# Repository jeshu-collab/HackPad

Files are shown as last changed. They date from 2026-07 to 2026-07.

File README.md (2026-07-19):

# HackPad1

HackPad1 is a custom 9-key macropad built using the Seeed XIAO RP2040. It includes a rotary encoder, a 128x32 OLED display, and per-key RGB lighting. The firmware is written using KMK, making it easy to customize key mappings and add new features.

This project was designed from scratch, including the PCB, enclosure, and firmware.

---

## Features

- 9-key mechanical macropad (3x3 layout)
- EC11 rotary encoder for volume control
- 128x32 OLED display
- Per-key RGB using SK6812MINI-E LEDs
- Powered by Seeed XIAO RP2040
- KMK firmware for easy customization
- Custom 2-piece 3D printed enclosure

---

## CAD Model

The enclosure is designed as a two-piece case.

- **Top Shell:** Holds the switches and has the outer frame.
- **Bottom Plate:** Closes the enclosure and supports the PCB.

### Overall View

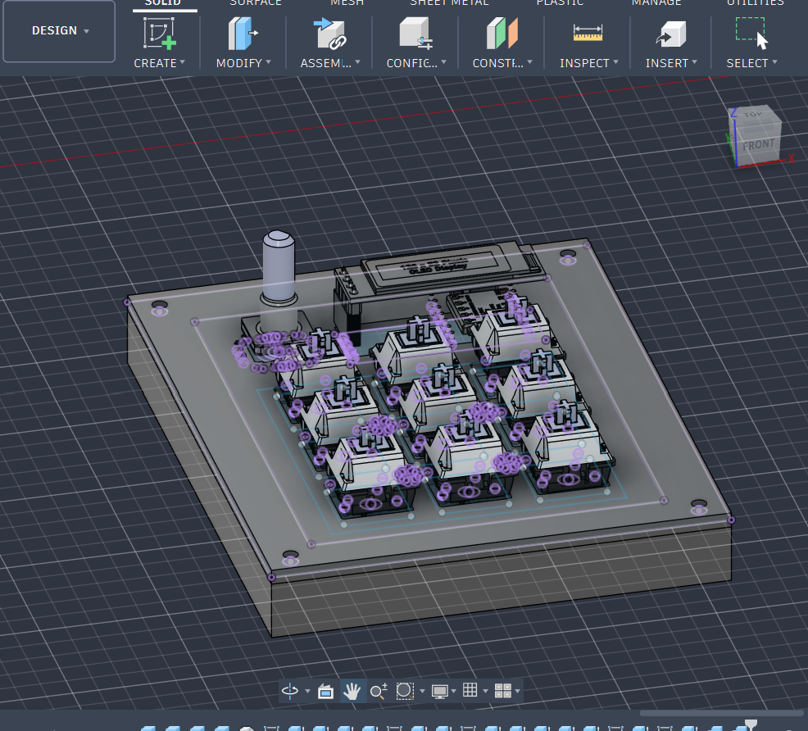
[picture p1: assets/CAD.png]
Overall Hackpad


### Case Assembly

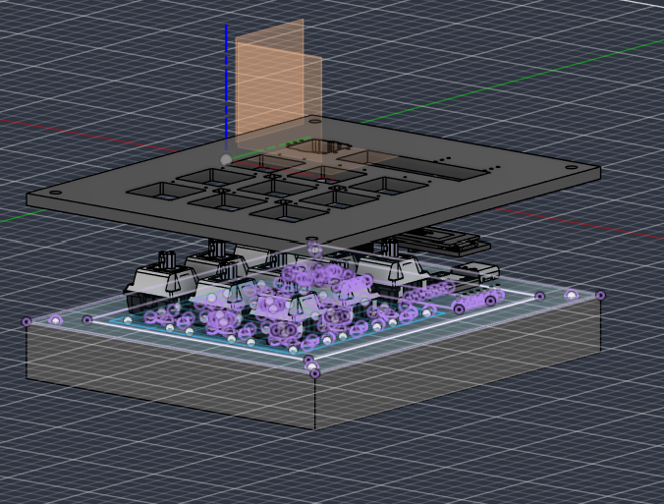
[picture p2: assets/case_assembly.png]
Case Assembly


---

## PCB

The PCB was designed in KiCad. It includes the switch matrix, rotary encoder, OLED display connections, RGB LEDs, and the XIAO RP2040.

### Schematic

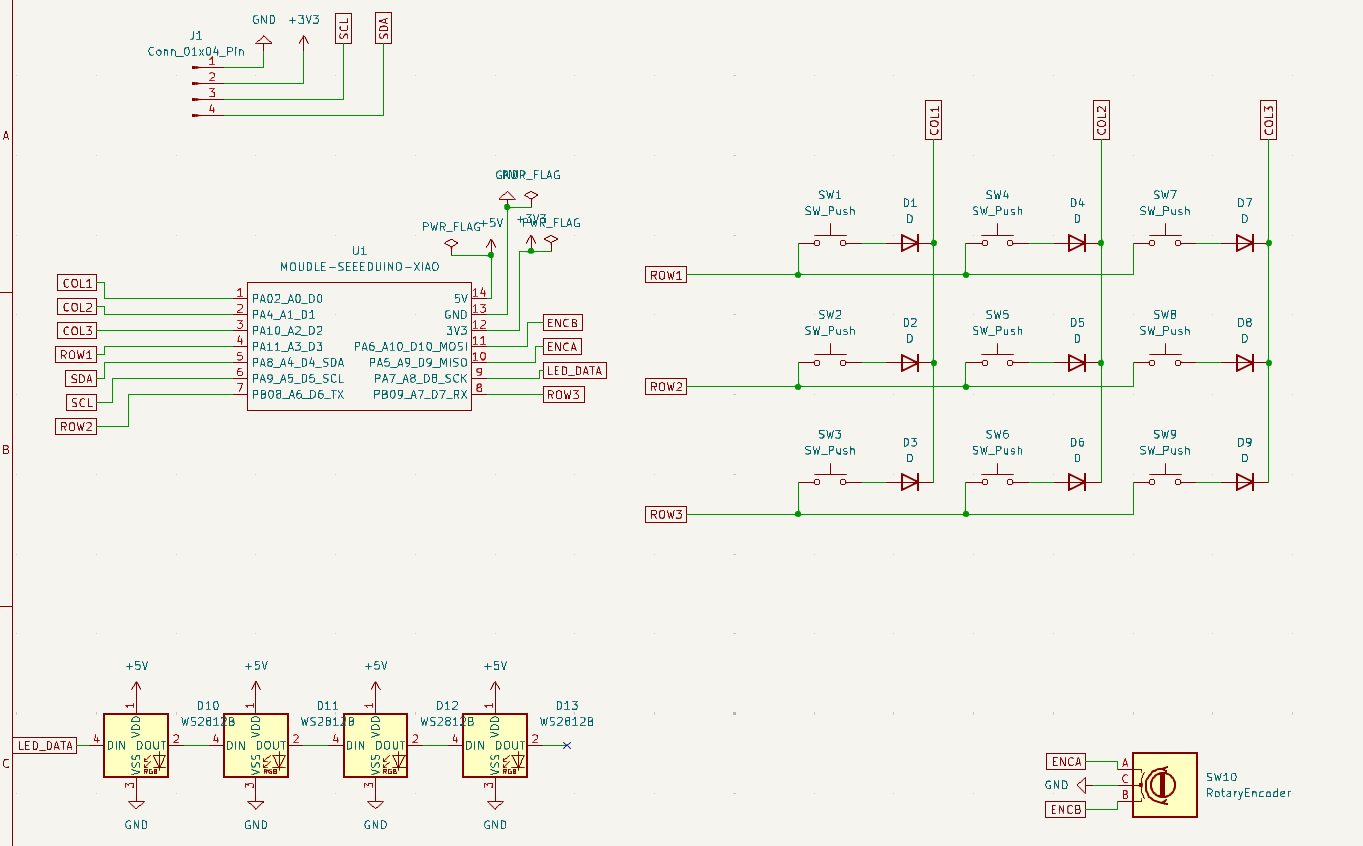
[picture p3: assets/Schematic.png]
Schematic


### PCB Layout

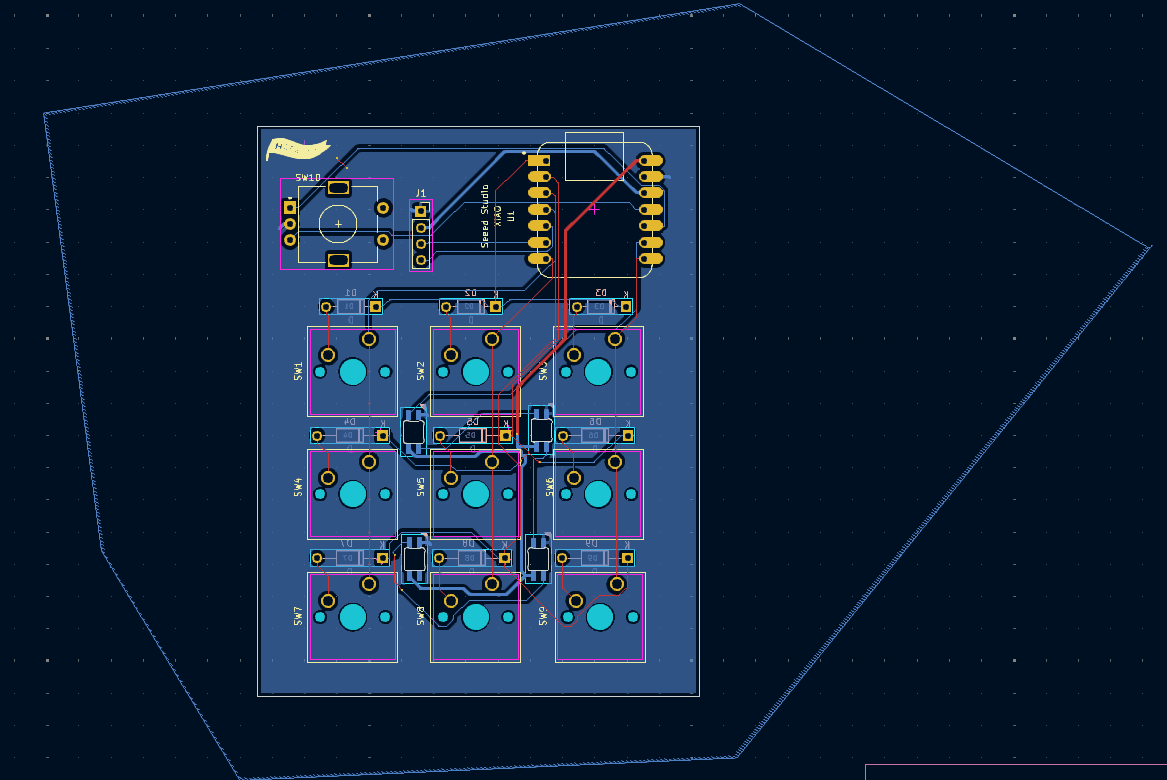
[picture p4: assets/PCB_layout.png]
PCB


---

## Firmware

The firmware is based on **KMK**.

Current functionality:

- Rotary encoder controls system volume.
- Pressing the encoder mutes/unmutes the audio.
- The 9 keys are currently mapped as number keys (1–9).
- OLED displays a startup message.

Key mappings can be easily changed by editing `main.py`.

---

## Bill of Materials (BOM)

| Component | Quantity |
|---|---:|
| Cherry MX Switches | 9 |
| Keycaps | 9 |
| 1N4148 Diodes | 9 |
| SK6812MINI-E RGB LEDs | 9 |
| 0.91" 128x32 OLED Display | 1 |
| EC11 Rotary Encoder | 1 |
| Seeed XIAO RP2040 | 1 |
| 3D Printed Enclosure | 1 Set |
| M3 Screws *(update after final assembly)* | As Required |

---

## Future Improvements

- Add multiple layers and shortcuts
- OLED status indicators
- RGB lighting effects
- VIA/Vial-style configuration (if supported)
- Improve case design after testing the first prototype

---

## Acknowledgements

This project was built as part of the Hack Club HackPad initiative.

Special thanks to the Hack Club community for the resources and guidance throughout the build.

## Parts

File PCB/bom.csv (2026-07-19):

Reference | Value | Datasheet | Footprint | Qty | DNP
D1,D2,D3,D4,D5,D6,D7,D8,D9 | D | ~ | -- mixed values -- | 9
D10,D11,D12,D13 | WS2812B | https://cdn-shop.adafruit.com/datasheets/WS2812B.pdf | Keyboard_Parts:MX_SK6812MINI-E | 4
J1 | Conn_01x04_Pin | ~ | Connector_PinSocket_2.54mm:PinSocket_1x04_P2.54mm_Vertical | 1
SW1,SW2,SW3,SW4,SW5,SW6,SW7,SW8,SW9 | SW_Push | ~ | Button_Switch_Keyboard:SW_Cherry_MX_1.00u_PCB | 9
SW10 | RotaryEncoder | ~ | Rotary_Encoder:RotaryEncoder_Alps_EC11E-Switch_Vertical_H20mm | 1
U1 | MOUDLE-SEEEDUINO-XIAO |  | footprints:XIAO-Generic-Hybrid-14P-2.54-21X17.8MM | 1

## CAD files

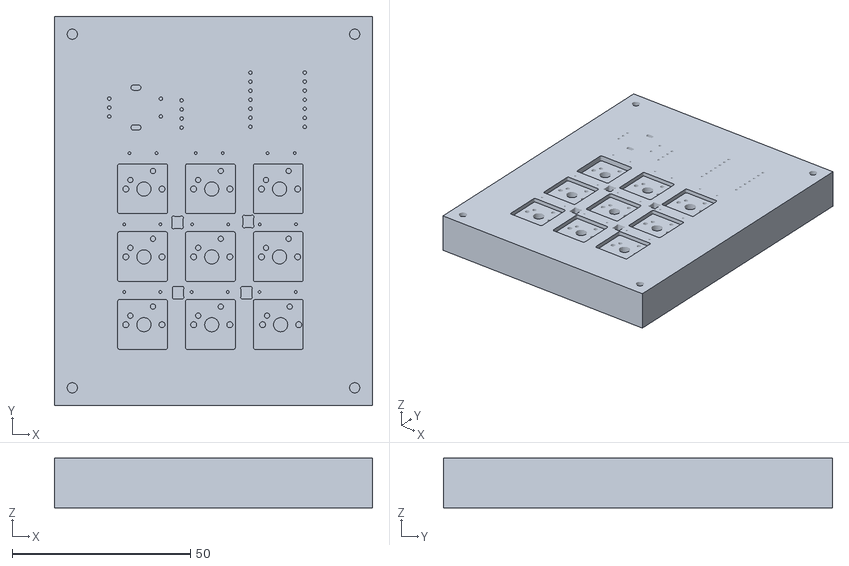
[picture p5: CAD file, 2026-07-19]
Production/Bottom.stl
89.3 x 109.3 x 14.0

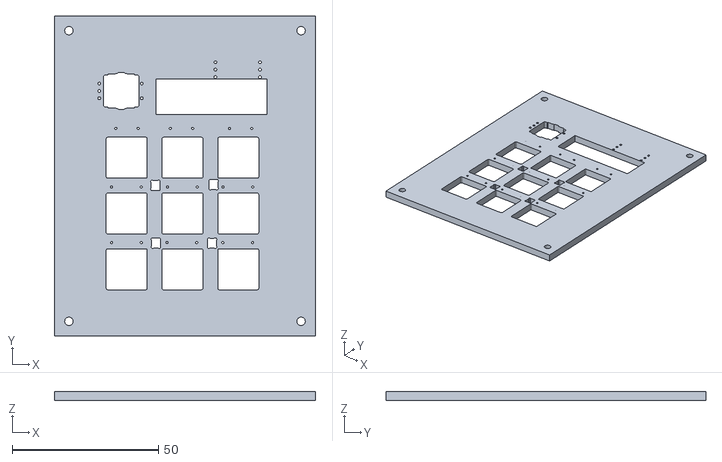
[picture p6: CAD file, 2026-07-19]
Production/Top.stl
89.3 x 109.3 x 3.00

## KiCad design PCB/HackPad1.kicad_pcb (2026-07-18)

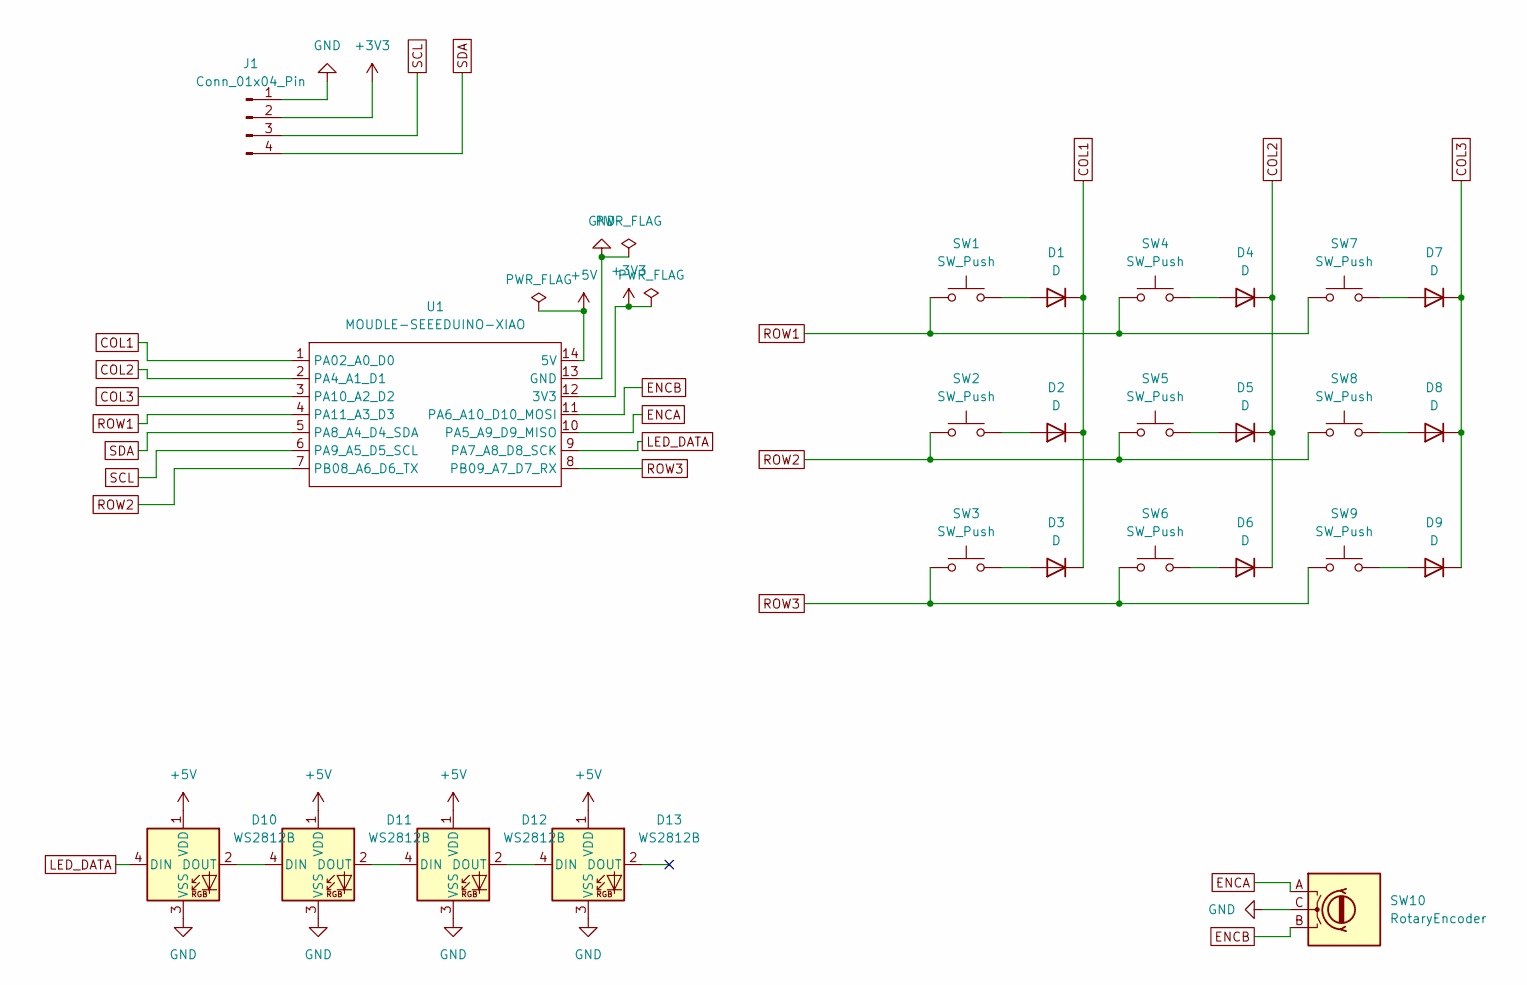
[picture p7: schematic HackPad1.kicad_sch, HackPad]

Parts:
D1, D2, D3: D; D_DO-35_SOD27_P7.62mm_Horizontal
D4, D5, D6, D7, D8, D9: D; D_DO-35_SOD27_P10.16mm_Horizontal
D10, D11, D12, D13: WS2812B; MX_SK6812MINI-E
J1: Conn_01x04_Pin; PinSocket_1x04_P2.54mm_Vertical
SW1, SW2, SW3, SW4, SW5, SW6, SW7, SW8, SW9: SW_Push; SW_Cherry_MX_1.00u_PCB
SW10: RotaryEncoder; RotaryEncoder_Alps_EC11E-Switch_Vertical_H20mm
U1: MOUDLE-SEEEDUINO-XIAO; XIAO-Generic-Hybrid-14P-2.54-21X17.8MM

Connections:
+3V3: J1.2, U1.12 (3V3)
+5V: D10.1 (VDD), D11.1 (VDD), D12.1 (VDD), D13.1 (VDD), U1.14 (5V)
COL1: D1.1 (K), D2.1 (K), D3.1 (K), U1.1 (PA02_A0_D0)
COL2: D4.1 (K), D5.1 (K), D6.1 (K), U1.2 (PA4_A1_D1)
COL3: D7.1 (K), D8.1 (K), D9.1 (K), U1.3 (PA10_A2_D2)
ENCA: SW10.A, U1.10 (PA5_A9_D9_MISO)
ENCB: SW10.B, U1.11 (PA6_A10_D10_MOSI)
GND: D10.3 (VSS), D11.3 (VSS), D12.3 (VSS), D13.3 (VSS), J1.1, SW10.C, U1.13 (GND)
LED_DATA: D10.4 (DIN), U1.9 (PA7_A8_D8_SCK)
unnamed: D1.2 (A), SW1.2
unnamed: D2.2 (A), SW2.2
unnamed: D3.2 (A), SW3.2
unnamed: D4.2 (A), SW4.2
unnamed: D5.2 (A), SW5.2
unnamed: D6.2 (A), SW6.2
unnamed: D7.2 (A), SW7.2
unnamed: D8.2 (A), SW8.2
unnamed: D9.2 (A), SW9.2
unnamed: D10.2 (DOUT), D11.4 (DIN)
unnamed: D11.2 (DOUT), D12.4 (DIN)
unnamed: D12.2 (DOUT), D13.4 (DIN)
ROW1: SW1.1, SW4.1, SW7.1, U1.4 (PA11_A3_D3)
ROW2: SW2.1, SW5.1, SW8.1, U1.7 (PB08_A6_D6_TX)
ROW3: SW3.1, SW6.1, SW9.1, U1.8 (PB09_A7_D7_RX)
SCL: J1.3, U1.6 (PA9_A5_D5_SCL)
SDA: J1.4, U1.5 (PA8_A4_D4_SDA)

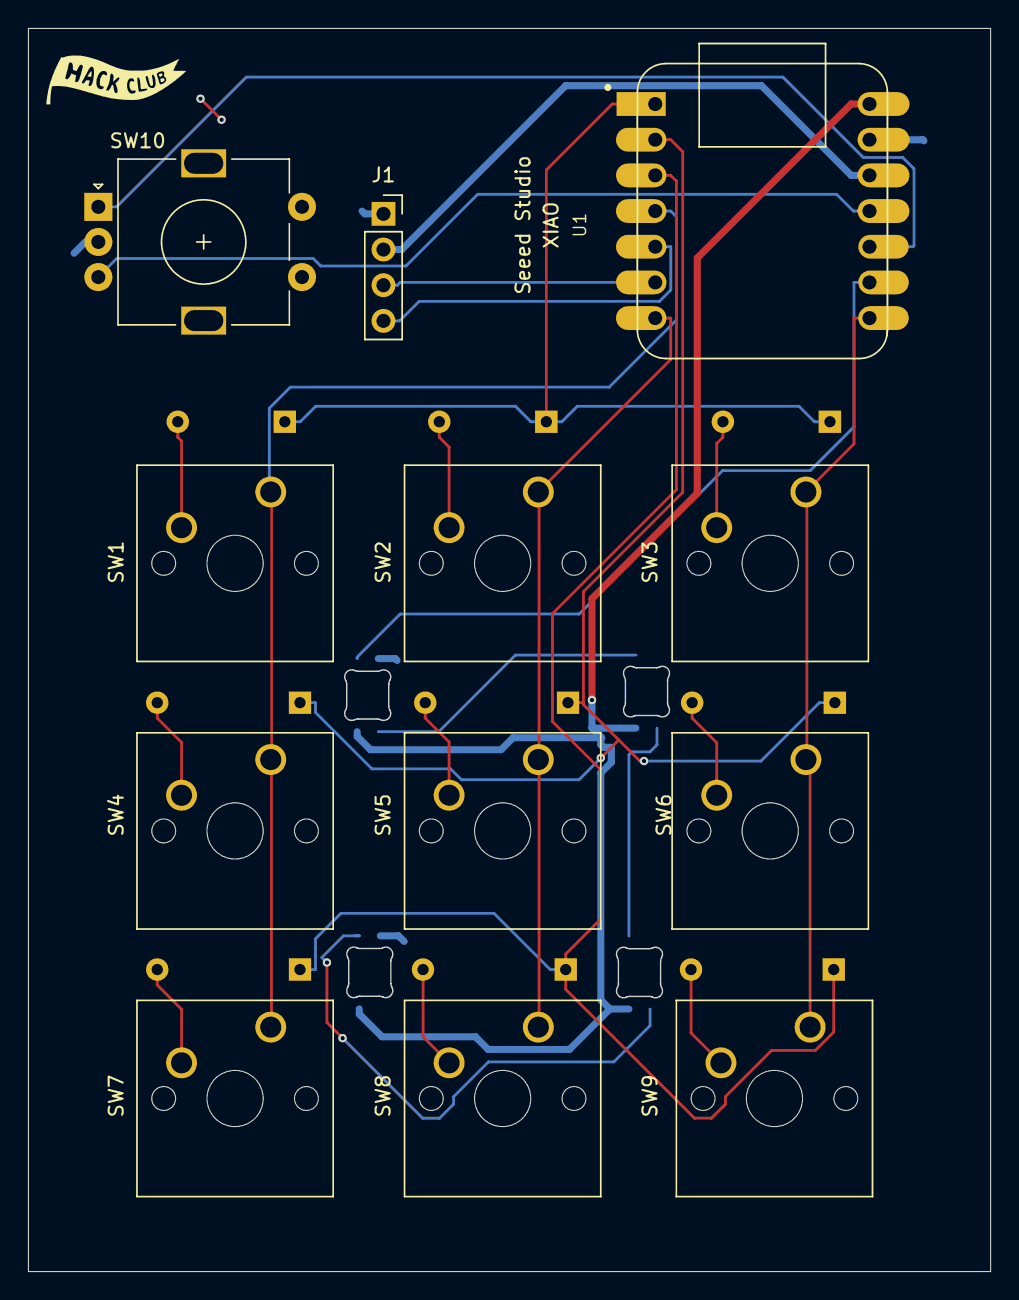
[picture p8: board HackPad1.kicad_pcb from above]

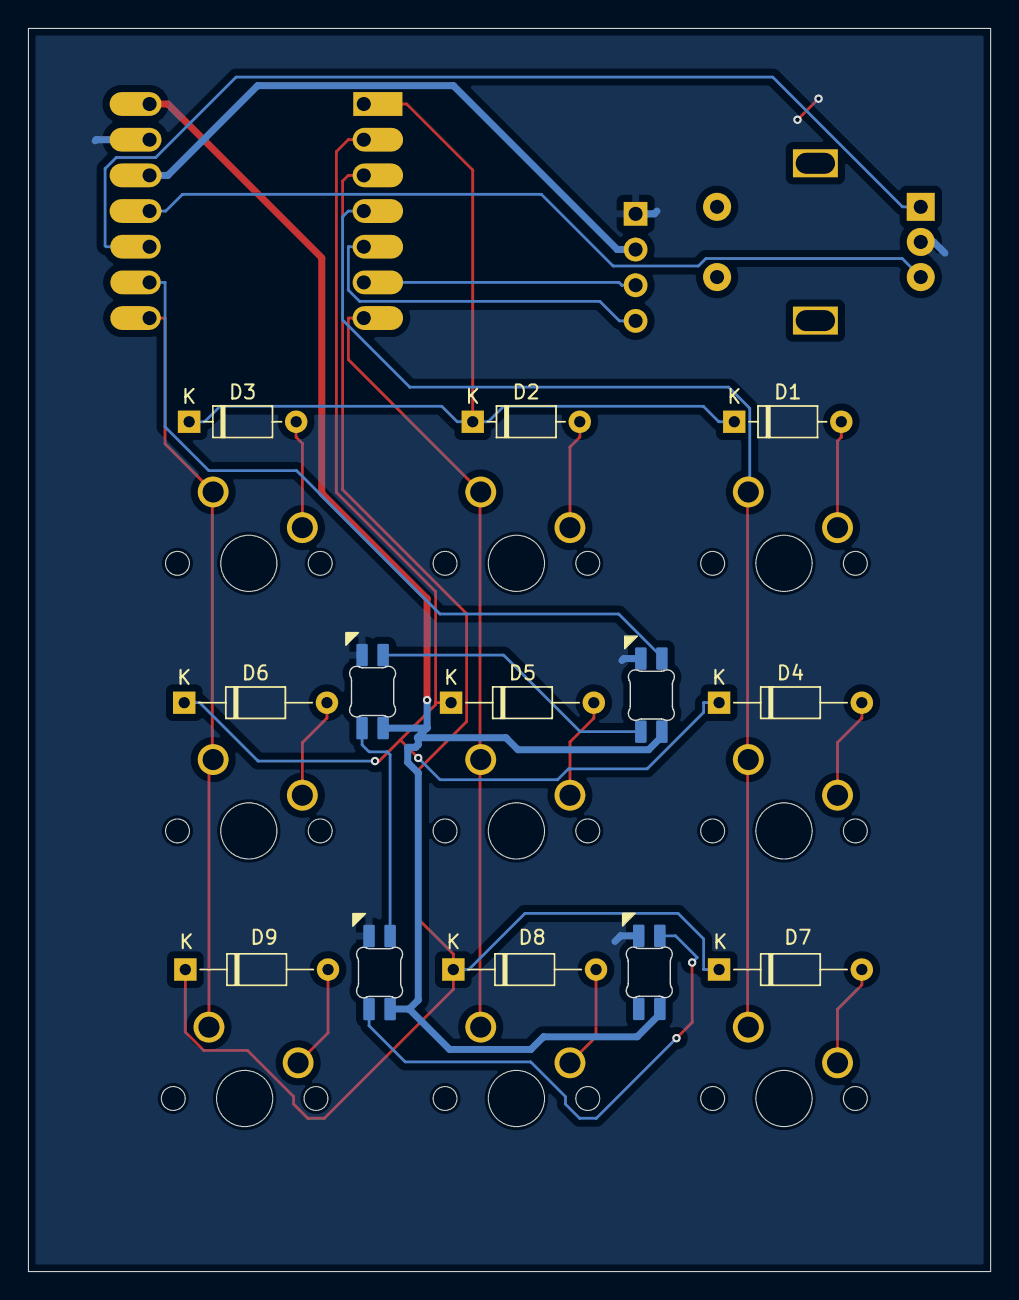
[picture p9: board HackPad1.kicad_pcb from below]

Board: 2 copper layers, 68.5 x 88.5 mm, 25 parts (9 on the bottom side), 26 nets.

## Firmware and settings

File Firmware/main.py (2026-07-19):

code = """import board
import busio
from kmk.kmk_keyboard import KMKKeyboard
from kmk.keys import KC
from kmk.scanners import DiodeOrientation
from kmk.modules.encoder import EncoderHandler
from kmk.modules.layers import Layers
from kmk.extensions.rgb import RGB
from kmk.extensions.display import Display, TextEntry
from kmk.extensions.display.ssd1306 import SSD1306

# Initialize the keyboard
keyboard = KMKKeyboard()

# Add standard modules
keyboard.modules.append(Layers())
encoder_handler = EncoderHandler()
keyboard.modules.append(encoder_handler)

# --- SWITCH MATRIX SETUP ---
keyboard.col_pins = (board.GP0, board.GP1, board.GP2)
keyboard.row_pins = (board.GP3, board.GP4, board.GP5)
keyboard.diode_orientation = DiodeOrientation.COL2ROW

# --- ENCODER SETUP ---
encoder_handler.pins = ((board.GP26, board.GP27, board.GP28, False),)
encoder_handler.map = [
    ((KC.VOLD, KC.VOLU, KC.MUTE),)
]

# --- RGB LED SETUP (SK6812MINI-E) ---
# Replace board.GP29 with your actual LED data pin from KiCad
rgb = RGB(
    pixel_pin=board.GP29,
    num_pixels=9, # Number of LEDs in your matrix
    val_limit=100, # Brightness limit
    hue_default=0,
    sat_default=255,
    val_default=100
)
keyboard.extensions.append(rgb)

# --- OLED DISPLAY SETUP (128x32) ---
# Replace GP7 (SDA) and GP6 (SCL) with your actual I2C pins
i2c_bus = busio.I2C(board.GP7, board.GP6)
display_driver = SSD1306(i2c=i2c_bus, device_address=0x3C)
display = Display(
    display=display_driver,
    entries=[
        TextEntry(text='Hackpad Ready!', x=0, y=0, y_anchor='M'),
    ],
    width=128,
    height=32,
    dim_time=10,
    dim_target=0.2,
    off_time=1200,
    return_to_base=True
)
keyboard.extensions.append(display)

# --- KEYMAP ---
keyboard.keymap = [
    [
        KC.N1, KC.N2, KC.N3,
        KC.N4, KC.N5, KC.N6,
        KC.N7, KC.N8, KC.N9
    ]
]

if __name__ == '__main__':
    keyboard.go()
"""

with open("main.py", "w") as f:
    f.write(code)

print("Hello")

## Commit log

2026-06-28 Learning pcb editor for HackPad
    [HackPad1.kicad_pcb, HackPad1.kicad_sch]
2026-06-28 pcb basics
    [HackPad1.kicad_pcb, HackPad1.kicad_sch]
2026-06-28 changed layout
    [HackPad1.kicad_pcb]
2026-06-29 designed pcb routing basics
    [HackPad1.kicad_pcb]
2026-06-29 design difficulty
    [HackPad1.kicad_pcb]
2026-06-29 layout 2
    [HackPad1.kicad_pcb]
2026-06-29 updated design basics
    [HackPad1.kicad_pcb]
2026-07-03 design 2
    [HackPad1.kicad_pcb]
2026-07-03 design 3
    [HackPad1.kicad_pcb]
2026-07-03 design 4
    [HackPad1.kicad_pcb]
2026-07-05 designed switch schematic
    [HackPad1.kicad_sch]
2026-07-05 designed microcontroller schematic
2026-07-05 added LED schimatic
    [HackPad1.kicad_sch]
2026-07-05 added led schematic
    [HackPad1.kicad_sch]
2026-07-05 all components schematic done
    [HackPad1.kicad_sch]
2026-07-05 added footprints for diode, switch, oled
    [HackPad1.kicad_sch]
2026-07-05 added LED footprints
    [HackPad1.kicad_sch]
2026-07-06 added all footprints
    [HackPad1.kicad_pcb, HackPad1.kicad_sch]
2026-07-06 updated switch pcb layout
    [HackPad1.kicad_pcb]
2026-07-06 updated diode pcb layout
2026-07-06 updated LED schematic(switched from 9 to 4)
    [HackPad1.kicad_sch]
2026-07-06 designed led pcb layout
    [HackPad1.kicad_pcb]
2026-07-06 added complete pcb layout need to start routing
    [HackPad1.kicad_pcb]
2026-07-06 added pcb edge cut
    [HackPad1.kicad_pcb]
2026-07-08 added all 3d models
    [94180A331_Brass Tapered Heat-Set Inserts for Plastic.STEP, 97763A456_18-8 Stainless Steel Button Head Hex Drive Screws.STEP, Cherry MX.STEP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]
2026-07-08 done eouting except power points
    [HackPad1.kicad_pcb]
2026-07-08 routing done
    [HackPad1.kicad_pcb]
2026-07-09 completed pcb design
    [HackPad1.kicad_sch]
2026-07-09 added hacclub sticker and did some minor changes
    [HackPad1.kicad_pcb]
2026-07-09 gerber generated
    [HackPad1-B_Cu.gbr, HackPad1-B_Mask.gbr, HackPad1-B_Paste.gbr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]
2026-07-14 design schematic changes
    [HackPad1.kicad_sch]
2026-07-14 design pcb changes
    [HackPad1.kicad_pcb]
2026-07-14 pcb old design change
    [HackPad1.kicad_pcb]
2026-07-18 resized pcb
    [HackPad1.kicad_pcb]
2026-07-19 rearranged the files as per the instructions
    [94180A331_Brass Tapered Heat-Set Inserts for Plastic.STEP, 97763A456_18-8 Stainless Steel Button Head Hex Drive Screws.STEP, Bottom.stl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]
2026-07-19 modified PCB folder
    [HackPad1.kicad_pcb, HackPad1.kicad_sch, bom.csv]
